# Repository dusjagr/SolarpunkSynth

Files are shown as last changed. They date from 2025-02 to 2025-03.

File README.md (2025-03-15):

# SolarpunkSynth 🌞🎹

A solar-powered synthesizer that creates experimental sounds, rhythmic patterns, and beats using minimal energy from the sun! This project embodies the spirit of solarpunk by combining sustainable energy with creative expression.

# Workshop Registration
https://sgmkcloud.ocloud.de/index.php/apps/forms/65qHgGpafZMqBaDL

## Description

The SolarpunkSynth is an ultra-low power consumption synthesizer that can be powered by:
- Silicon solar cells
- DIY DSSC (Dye-sensitized solar cells)
- Alternative power sources (mud batteries, potato power, coconut energy)
- Nearly depleted batteries (due to extremely low power requirements)

## Project Variants

This repository contains two versions of the SolarpunkSynth:

### 1. Original SolarpunkSynth
Located in [`/SolarPunkSynth`](./SolarPunkSynth)
- The original version of the solar-powered synthesizer
- Simple and elegant design
- Perfect for beginners and workshops
- Includes complete documentation and assembly instructions

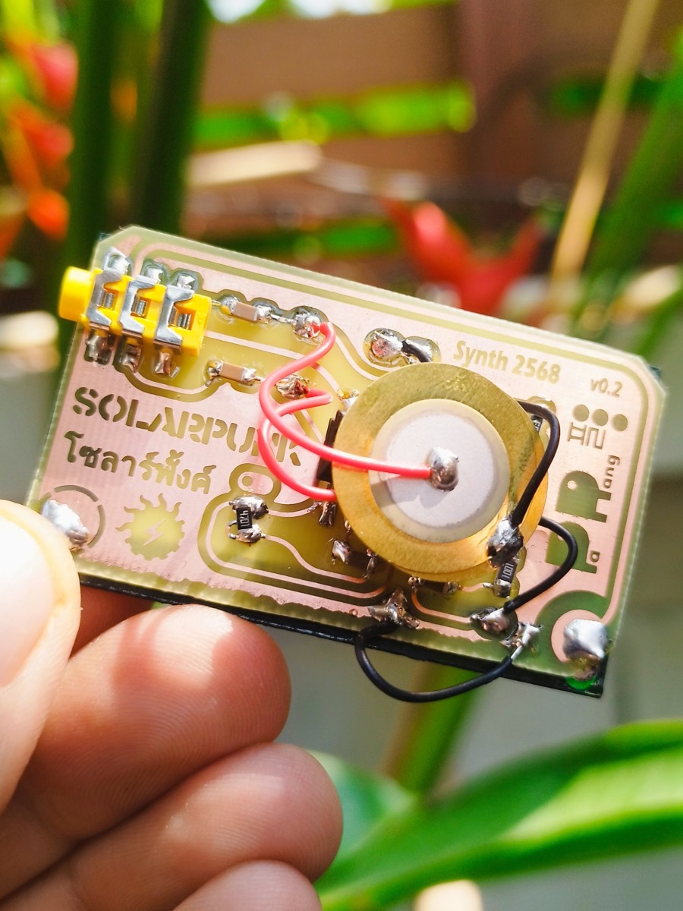
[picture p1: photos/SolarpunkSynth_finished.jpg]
Finished SolarpunkSynth


### 2. Digilog Edition
Located in [`/SolarSynth_digilog`](./SolarSynth_digilog)
- Enhanced version with digital-inspired aesthetics
- Developed for the Digilog exhibition in Taipei, Taiwan
- Features artistic PCB design with custom graphics
- Same core functionality with a unique visual style

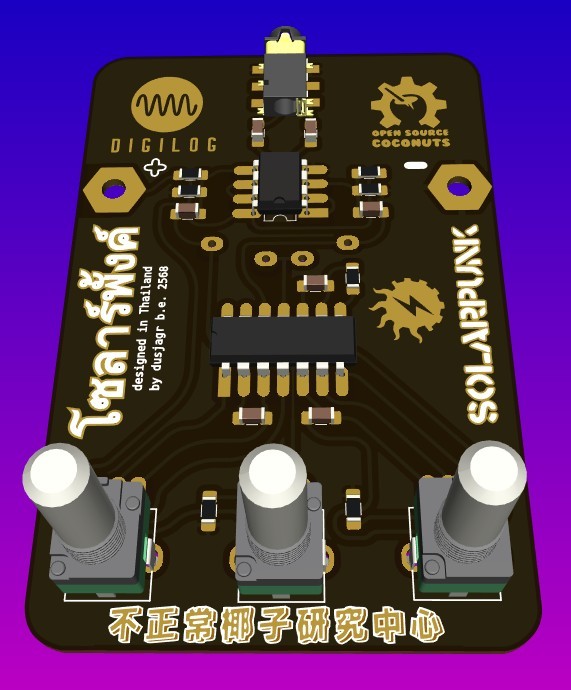
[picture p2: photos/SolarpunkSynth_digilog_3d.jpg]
SolarpunkSynth Digilog Edition


## Technical Details

The synthesizer is built around these key features:
- Based on hex-inverter chip (74HC14)
- Three interdependent oscillators coupled through piezo discs
- Ultra-low energy consumption (<0.5mA)
- Audio output via 3.5mm jack
- Organic, variable rhythms through unstable circuit states
- KiCad PCB design files included

### Technical Differences Between Variants

#### Original SolarpunkSynth
- Simple and robust circuit design
- Direct audio output from oscillator circuit
- Basic component selection for easy assembly
- Standard PCB layout optimized for functionality
- Ideal for workshops and educational purposes

#### Digilog Edition Enhancements
- Added MCP6002 dual op-amp for improved audio output buffering
- Enhanced signal conditioning with additional filtering capacitors
- Modified component values for better stability
- Custom footprint library optimized for artistic PCB layout
- Artistic PCB design with custom traces and visual elements
- ENIG finish recommended for superior aesthetic presentation
- Optional acrylic cover design for finished look and protection

### Schematic
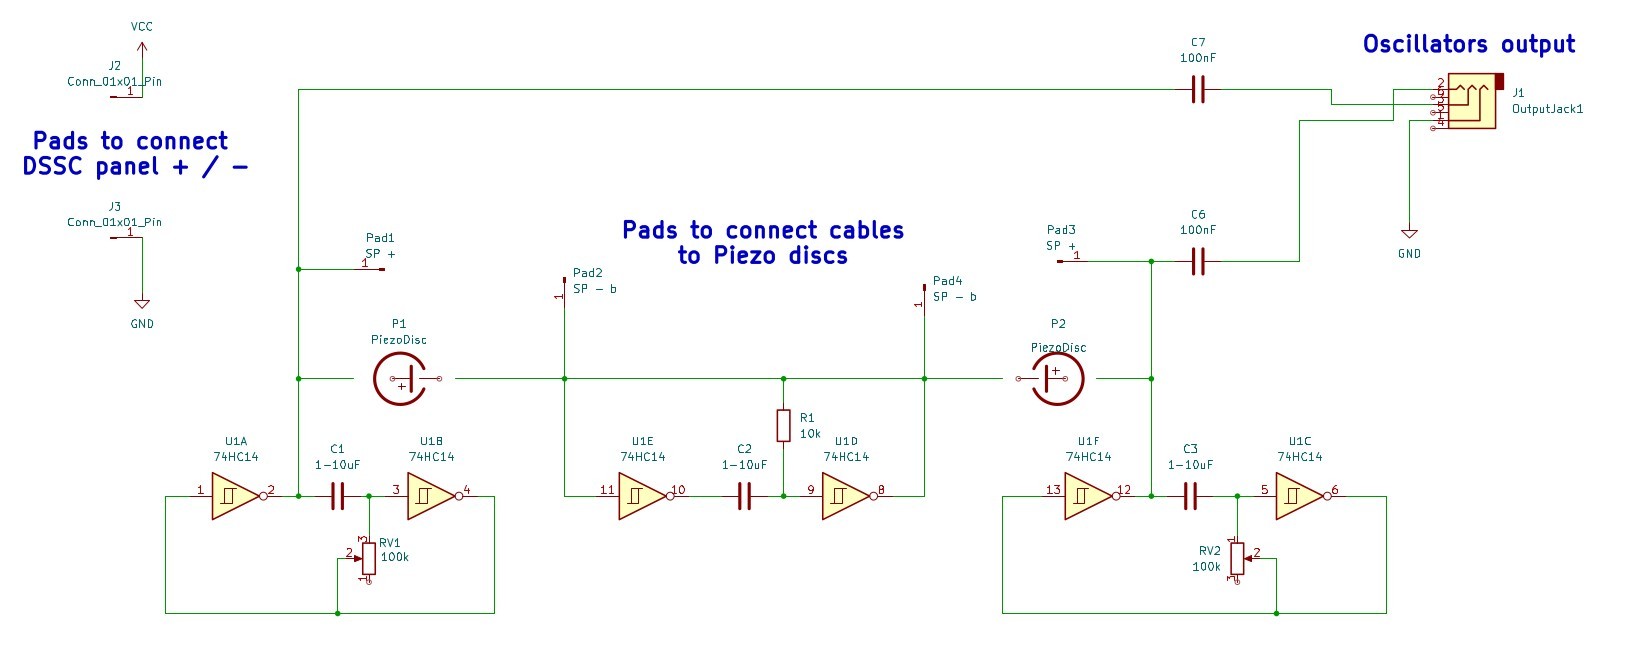
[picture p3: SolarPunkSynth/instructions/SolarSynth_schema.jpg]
SolarSynth Schema


You can also view the [minimal schematic as PDF](./SolarPunkSynth/instructions/DSSC_Synthminimal_schema.pdf).

## Assembly Instructions

### Original SolarpunkSynth

For the original SolarpunkSynth version:
- [Detailed Soldering Guide (PDF)](./SolarPunkSynth/instructions/SolderInstruction.pdf)
- [Soldering Guide (SVG)](./SolarPunkSynth/instructions/SolderInstruction.svg)
- **[Complete step-by-step assembly instructions](./SolarPunkSynth/README.md#detailed-step-by-step-assembly-instructions)** are included in the SolarPunkSynth README.md

### Digilog Edition

Instruction photos are available:

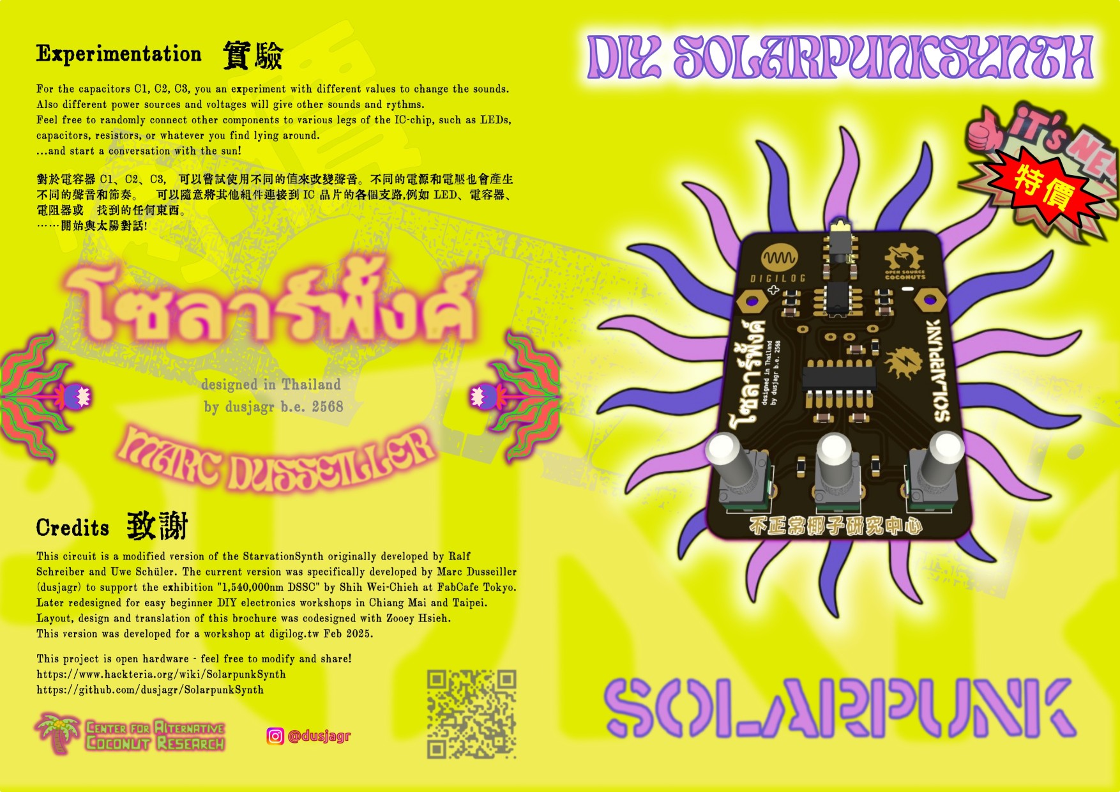
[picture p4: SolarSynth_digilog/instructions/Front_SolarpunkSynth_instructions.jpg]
Front Soldering Instructions

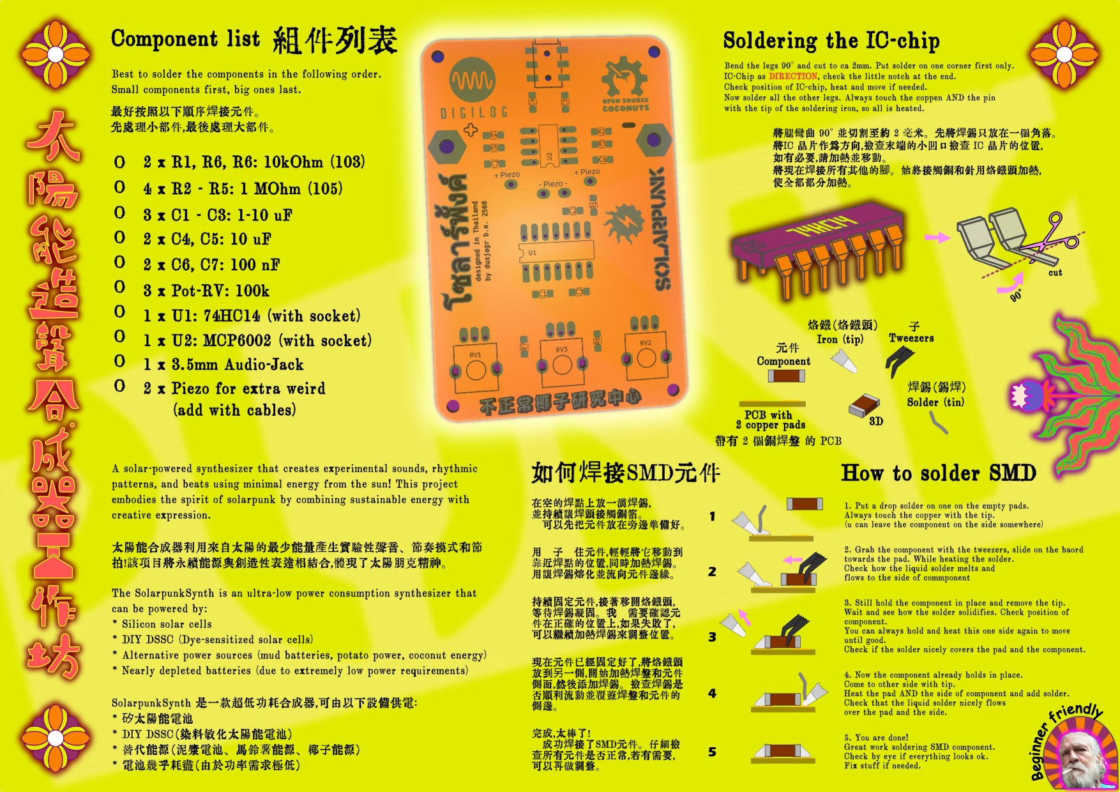
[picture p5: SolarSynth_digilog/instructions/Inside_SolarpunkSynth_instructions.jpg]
Inside Soldering Instructions


For the Digilog edition, additional documentation is available:
- [Leaflet Format Instructions (PDF)](./SolarSynth_digilog/instructions/SolarpunkSynth_SolderInstruction_leaflet.pdf)
- [Inside Pages (PDF)](./SolarSynth_digilog/instructions/SolarpunkSynth_SolderInstruction_leaflet_inside.pdf)
- [Outside Pages (PDF)](./SolarSynth_digilog/instructions/SolarpunkSynth_SolderInstruction_leaflet_outside.pdf)

## Repository Contents

- [`/SolarPunkSynth`](./SolarPunkSynth) - Original version KiCad files and documentation
  - [`/002_SolarPunkSynth_footprints.pretty`](./SolarPunkSynth/002_SolarPunkSynth_footprints.pretty) - Custom footprints for the PCB
  - [`/MASK`](./SolarPunkSynth/MASK) - PCB mask files and design assets
  - [`/instructions`](./SolarPunkSynth/instructions) - Assembly guides and schematics
  - [`/svg2shenzhen`](./SolarPunkSynth/svg2shenzhen) - SVG files for PCB artwork

- [`/SolarSynth_digilog`](./SolarSynth_digilog) - Digilog edition KiCad files
  - [`/3d_models`](./SolarSynth_digilog/3d_models) - 3D models of components
  - [`/DIY_pcb`](./SolarSynth_digilog/DIY_pcb) - DIY PCB patterns and masks for custom fabrication
  - [`/acrylicCover_digilog`](./SolarSynth_digilog/acrylicCover_digilog) - Design files for the optional acrylic protective cover
  - [`/gerber`](./SolarSynth_digilog/gerber) - Manufacturing files
  - [`/instructions`](./SolarSynth_digilog/instructions) - Enhanced assembly guides in multiple formats
  - [`/svg2shenzhen`](./SolarSynth_digilog/svg2shenzhen) - Custom PCB artwork files
  - [`BOM.ods`](./SolarSynth_digilog/BOM.ods) - Detailed bill of materials in OpenDocument Spreadsheet format

- [`/photos`](./photos) - Project photos and workshop documentation

## DIY PCB Fabrication

For those interested in creating their own PCBs at home or in makerspaces, the Digilog edition includes DIY PCB files:
- [`SolarSynth_MASK.png`](./SolarSynth_digilog/DIY_pcb/SolarSynth_MASK.png) - Printable mask pattern for toner transfer or photolithography
- [`SolarSynth_digilog_MASK.svg`](./SolarSynth_digilog/DIY_pcb/SolarSynth_digilog_MASK.svg) - Vector version of the mask for scaling and modifications

These files can be used with common DIY PCB fabrication methods like toner transfer, photolithography, or CNC milling.

## Acrylic Cover

The Digilog edition offers an optional aesthetic acrylic cover:
- [`acrylCover_digilog.dxf`](./SolarSynth_digilog/acrylicCover_digilog/acrylCover_digilog.dxf) - CAD file for laser cutting
- [`drawing.svg`](./SolarSynth_digilog/acrylicCover_digilog/drawing.svg) - Vector drawing for preview and modifications

The acrylic cover enhances the visual appeal while providing protection to the electronics.

## Workshop Information

A solar-powered synthesizer that creates experimental sounds, rhythmic patterns, and beats using minimal energy from the sun! This project embodies the spirit of solarpunk by combining sustainable energy with creative expression.

<figure>
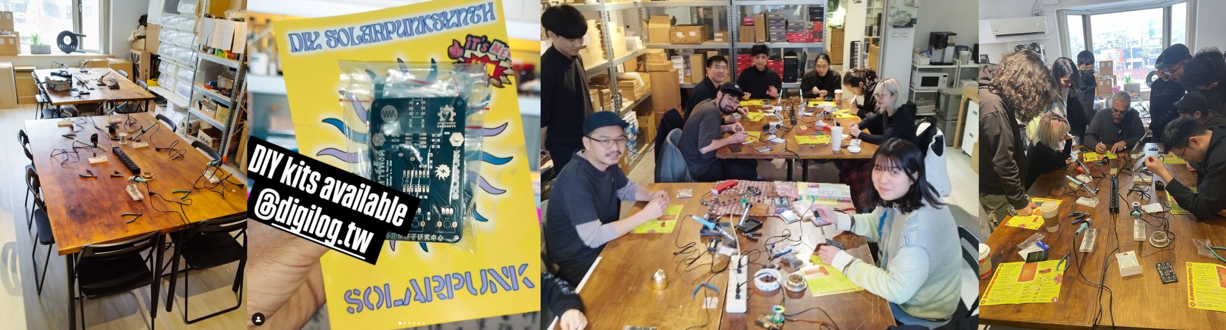
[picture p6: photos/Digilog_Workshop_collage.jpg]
Workshop Collage
  
  <figcaption><em>Impressions from the workshop at digilog, Taipei, February 2025</em></figcaption>
</figure>

This project is designed to be beginner-friendly and has been successfully taught in workshops across various locations including:
- Taipei, Taiwan (Digilog)
- Chiang Mai, Thailand
- Tokyo, Japan (FabCafe)

No prior electronics knowledge is required - just enthusiasm for experimental sounds and solar-powered creativity!

<figure>
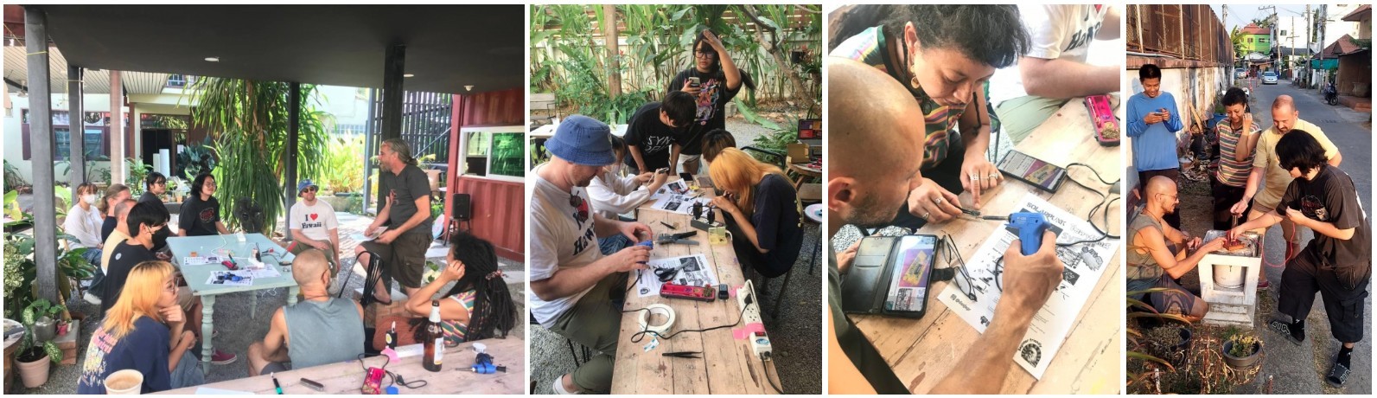
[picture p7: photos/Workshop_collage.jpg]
Workshop Collage
  
  <figcaption><em>Photos from the SolarpunkSynth Workshop at Parang Cafe & Art Stay, Chiang Mai, Thailand</em></figcaption>
</figure>

## Credits

This circuit is a modified version of the StarvationSynth originally developed by Ralf Schreiber and Uwe Schüler. The current version was specifically developed by Marc Dusseiller (dusjagr) to support the exhibition "1,540,000nm DSSC" by Shih Wei-Chieh at FabCafe Tokyo.

### Tools Used
- [svg2shenzhen](https://github.com/badgeek/svg2shenzhen) - An Inkscape extension that converts SVG drawings to KiCad PCB layouts, allowing for artistic and unrestricted PCB designs with support for any kind of shapes, drill pads, and edge cuts. Special thanks to Budi Prakosa ([@badgeek](https://github.com/badgeek)) for creating this amazing tool!
- KiCad - PCB design software

## Links

- [Project Wiki](https://www.hackteria.org/wiki/SolarpunkSynth)
- [Hackteria Network](http://hackteria.org/)
- [SGMK](https://mechatronicart.ch/)
- [Bitwäscherei Hackerspace](https://bitwaescherei.ch/)

## License

This project is open hardware - feel free to modify and share!

This project is licensed under the CERN Open Hardware License Version 2 - Permissive (CERN-OHL-P v2). This means you are free to:
- Study
- Modify
- Make
- Distribute

without any obligation to share your changes or modifications.

For more details, see the [LICENSE](./LICENSE) file.

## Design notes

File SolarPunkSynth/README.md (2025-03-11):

# Original SolarpunkSynth

This is the original version of the SolarpunkSynth - a solar-powered synthesizer designed for workshops and DIY enthusiasts.

Original SolarpunkSynth

## Features
- Simple and elegant PCB design
- Perfect for beginners and workshops
- Complete documentation and assembly instructions included
- Ultra-low power consumption (<0.5mA)
- Three interdependent oscillators

## Directory Contents
- `/002_SolarPunkSynth_footprints.pretty/` - Custom footprints for the PCB
- `/MASK/` - PCB mask files and design assets
- `/instructions/` - Detailed assembly guides and schematics
  - `SolderInstruction.pdf` - Step-by-step soldering guide
  - `SolderInstruction.svg` - Vector version of instructions
  - `SolarSynth_schema.jpg` - Circuit schematic
  - `DSSC_Synthminimal_schema.pdf` - Minimal schematic version
- `/svg2shenzhen/` - SVG files for PCB artwork

## Detailed Step-by-Step Assembly Instructions

Detailed soldering instructions are provided to help you build your own SolarpunkSynth:

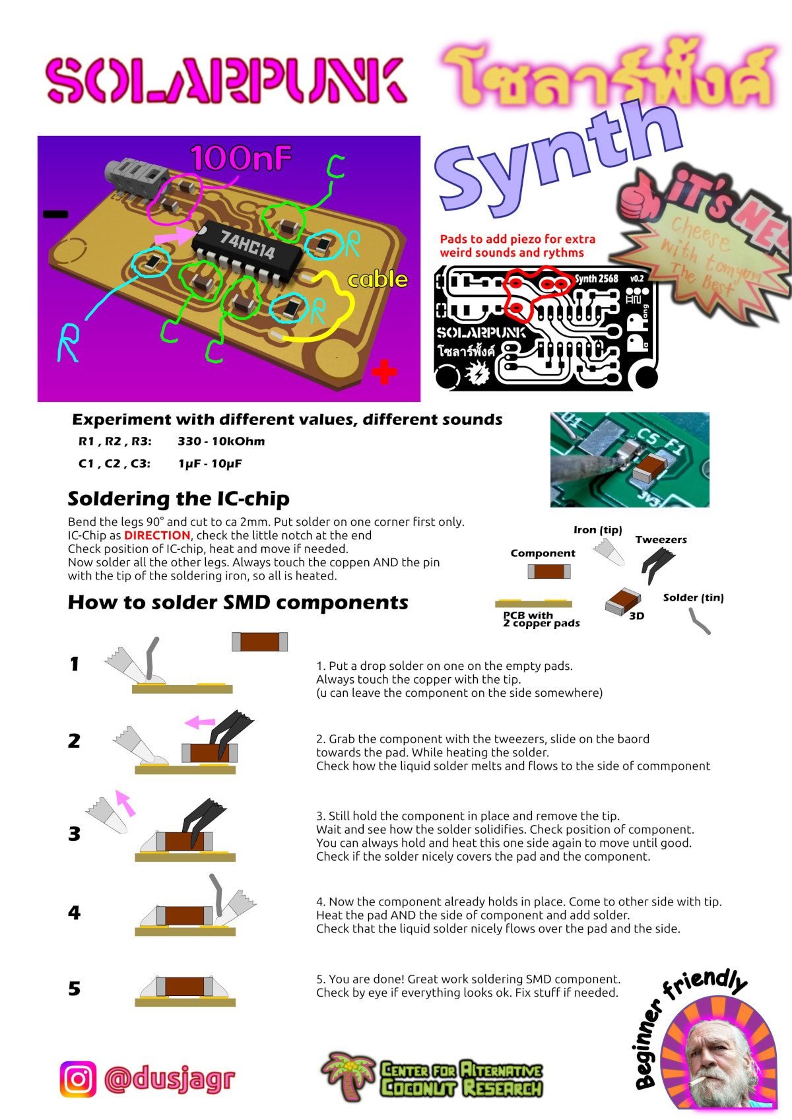
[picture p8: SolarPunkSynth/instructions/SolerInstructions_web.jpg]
Soldering Instructions


### Bill of Materials
- 1x PCB board
- 1x IC socket (14-pin DIP)
- 1x 74HC14 hex Schmitt trigger IC
- 3x Piezo discs
- 1x 3.5mm audio jack
- 1x 9V battery clip or solar cell connector
- Resistors:
  - 1x 1M ohm
  - 1x 470K ohm
  - 1x 330K ohm
  - 2x 100K ohm
  - 1x 10K ohm
- Capacitors:
  - 3x 0.1μF (ceramic)
  - 2x 10μF (electrolytic)

### Tools Required
- Soldering iron
- Solder (lead-free recommended)
- Wire cutters
- Tweezers (optional but helpful)
- Multimeter (for troubleshooting)

### Assembly Steps

#### 1. Prepare Your Workspace
- Find a well-ventilated area with good lighting
- Have all components sorted and ready
- Make sure your soldering iron is heated and ready

#### 2. Begin with Resistors
- Start by soldering the resistors first, as they are the lowest-profile components
- The resistors go in the positions marked on the PCB silkscreen
- Bend the resistor leads at 90° angles to match the hole spacing
- Insert them flush against the board
- Solder each connection and clip excess leads

#### 3. Add Capacitors
- Next, add the ceramic capacitors (0.1μF)
- For the electrolytic capacitors (10μF), make sure to observe the correct polarity - the negative side is marked with a stripe and should match the marking on the PCB

#### 4. Install the IC Socket
- Orient the socket so the notch matches the silkscreen
- Solder two opposite corner pins first to secure it in place
- Then solder the remaining pins

#### 5. Add the Audio Jack
- Insert the 3.5mm audio jack into its designated position
- Ensure it's sitting flat against the board
- Solder all pins securely

#### 6. Attach Piezo Discs
- Each piezo disc should be connected to its marked position
- The discs can be connected directly to the PCB or with short wires for flexibility
- For direct mounting, solder the piezo disc connections directly to the board
- For flexible mounting, solder short wires to the piezos and then to the board

#### 7. Connect Power
- Attach the battery clip or solar cell connector
- Make sure to observe correct polarity (red wire to + and black wire to -)

#### 8. Insert the IC
- Only after all other components are soldered, insert the 74HC14 IC into the socket
- Make sure the notch on the IC aligns with the notch on the socket
- Press firmly but gently to seat the IC properly

#### 9. Testing
- Connect a 9V battery or solar cell
- Plug headphones or an amplifier into the audio jack
- Tap or apply pressure to the piezo discs to create sound variations
- The circuit should immediately start generating sound

#### 10. Troubleshooting
If the circuit doesn't work:
- Check all solder joints for cold solder or bridges
- Verify the IC is correctly oriented and seated properly
- Confirm proper polarity of electrolytic capacitors and power connection
- Test voltage at various points with a multimeter
- Ensure the piezo discs are properly connected

### Playing Your SolarpunkSynth
- The synthesizer creates sounds through the interaction of three oscillators
- Each piezo disc influences one oscillator
- Try tapping, pressing, or even breathing on the piezo discs to change the sounds
- Experiment with different light intensities on the solar cell to alter sound characteristics
- Try connecting different audio outputs (headphones, amplifiers, speakers)

## Workshop Tips
- Recommended for groups of 5-15 participants
- Workshop duration: 2-3 hours
- No prior electronics experience required
- Tools needed: Soldering iron, solder, wire cutters

## Workshop Experience

SolarpunkSynth Workshop Experience

The SolarpunkSynth has been successfully used in numerous workshops, helping participants learn about electronics, solar power, and sound synthesis in an engaging hands-on environment.

## License
This project is licensed under the CERN Open Hardware License Version 2 - Permissive (CERN-OHL-P v2).

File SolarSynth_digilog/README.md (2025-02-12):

# SolarpunkSynth Digilog Edition

This is the Digilog edition of the SolarpunkSynth, specially developed for the Digilog exhibition in Taipei, Taiwan. This version features an artistic PCB design while maintaining the core functionality of the original SolarpunkSynth.

SolarpunkSynth Digilog Edition

## Features
- Enhanced PCB design with digital-inspired aesthetics
- Artistic circuit traces and visual elements
- Exhibition-ready presentation
- Improved audio output stage with op-amp buffer
- Ultra-low power consumption (<0.5mA)

## Technical Enhancements
- Added MCP6002 dual op-amp for better audio output buffering
- Enhanced signal conditioning with additional filtering
- Modified component values for improved stability
- Custom footprint library optimized for artistic PCB layout
- Polarized capacitors for better power filtering

## Directory Contents
- `/3d_models/` - 3D models of components for visualization
- `/gerber/` - Manufacturing files for PCB production
- `/svg2shenzhen/` - Custom PCB artwork files

## Exhibition History
- Digilog Exhibition, Taipei, Taiwan
- Part of the exploration of digital aesthetics in analog circuits
- Demonstrates the intersection of art and technology

## Technical Specifications
- Based on 74HC14 hex-inverter chip
- Three coupled oscillators using piezo discs
- MCP6002 dual op-amp for audio buffering
- Solar-powered operation
- 3.5mm audio output
- Artistic PCB design with custom traces

## PCB Design Process
The artistic PCB design was created using:
- [svg2shenzhen](https://github.com/badgeek/svg2shenzhen) - An Inkscape extension that transforms SVG artwork into KiCad PCB layouts, enabling complete creative freedom in PCB design with support for any shape and custom drill sizes
- Custom artwork designed specifically for the Digilog exhibition
- Careful consideration of both aesthetic and functional aspects

## Manufacturing Notes
- Gerber files are provided in the `/gerber/` directory
- PCB specifications:
  - 2-layer board
  - Custom silkscreen artwork
  - ENIG finish recommended for best aesthetic results

## Assembly
While the assembly process is similar to the original SolarpunkSynth, this version includes additional components:
1. MCP6002 dual op-amp in DFN-8 package
2. Additional filtering capacitors
3. Modified resistor values for the op-amp stage

Please refer to the schematic for detailed component values and connections.

## License
This project is licensed under the CERN Open Hardware License Version 2 - Permissive (CERN-OHL-P v2).

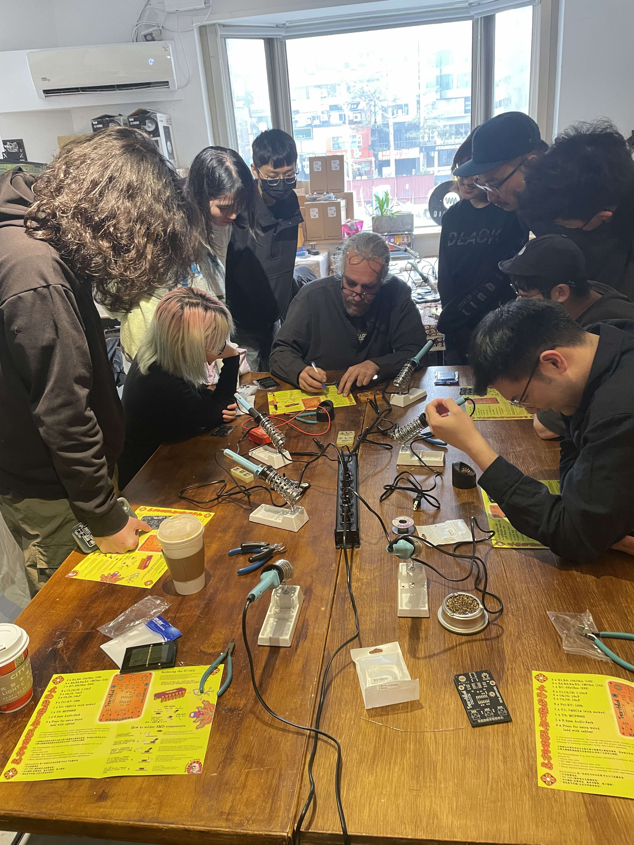
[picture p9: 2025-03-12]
photos/digilogWorkshop_02.jpg

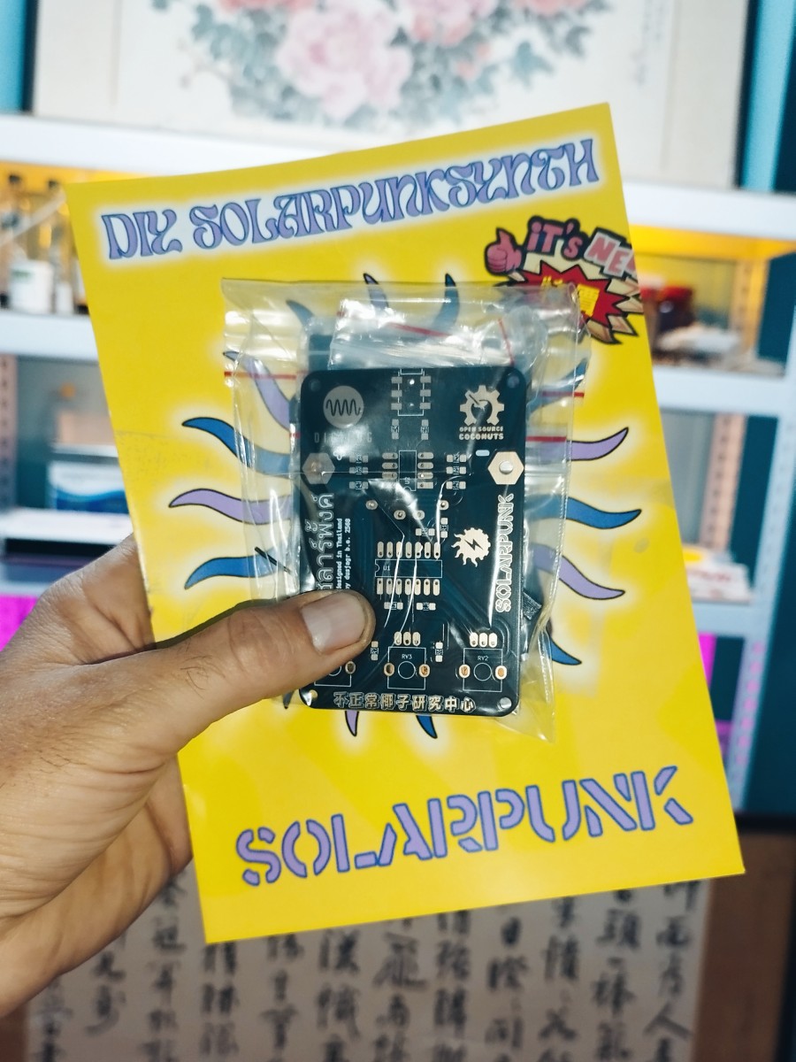
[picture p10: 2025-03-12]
photos/SolarpunkSynth_KIT.jpg

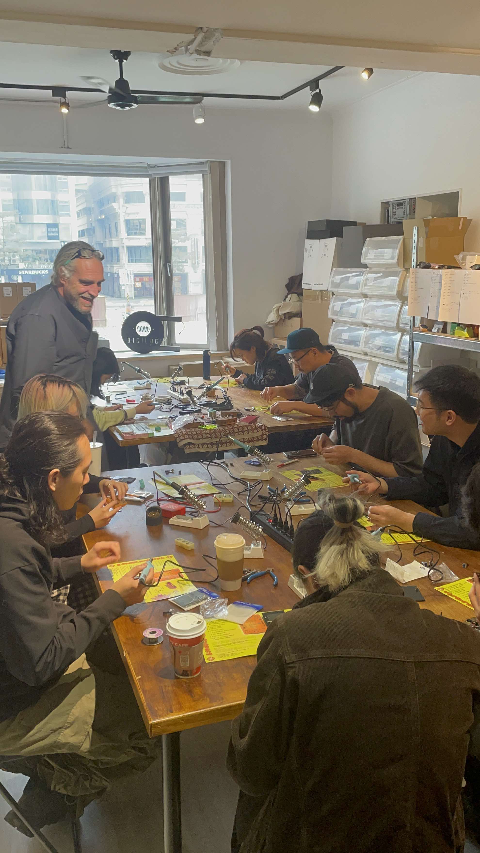
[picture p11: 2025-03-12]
photos/digilogWorkshop_01.jpg

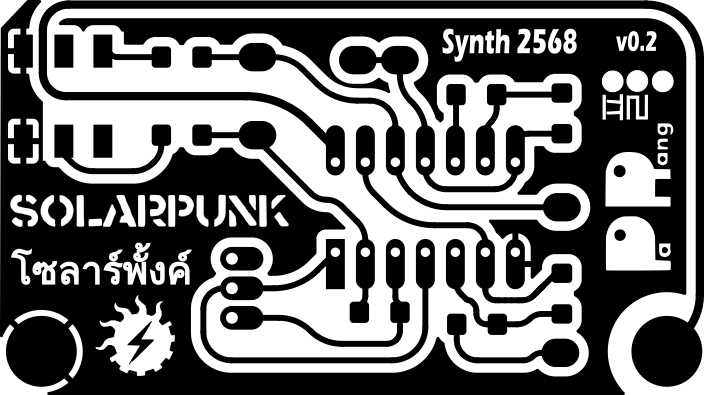
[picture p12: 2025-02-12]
SolarPunkSynth/MASK/SolarpunkSynth_parang.png

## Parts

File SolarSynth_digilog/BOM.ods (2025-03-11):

Id | Designator | Footprint | Quantity | Designation | Supplier and ref
10 | C3,C2,C1 | C_1210_noGND | 3 | 1-10uF
5 | C4,C5 | C_1210_noGND | 2 | C_Polarized
8 | C7,C6 | C_1210_noGND | 2 | 100nF
7 | edge1 | board_digilog | 1 | 5VBoard
11 | J1 | AUDIO-JACK-3.5mm_SMD_Hole | 1 | OutputJack1
2 | J3,J2 | SolarPad_VCC | 2 | Conn_01x01_Pin
12 | P1,P2 | Piezo_20mm | 2 | PiezoDisc
3 | Pad1,Pad3 | SolderPad_small | 2 | SP +
16 | Pad4,Pad2 | SolderPad_small | 2 | SP - b
6 | R1,R6 | R_1206_noGND | 2 | 10k
1 | R5,R4,R2,R3 | R_1206_noGND | 4 | 1M
14 | R7 | R_1206_noGND | 1 | 22k
4 | Ref** | graphix_digilog | 1 | Val**
17 | Ref** | back_graphix_digilog | 1 | Val**
13 | RV2,RV3,RV1 | RD901F-ALPHA-3D_longpads | 3 | 100k
15 | U1 | DIP-14_W7.62mm_LongerPads | 1 | 74HC14
9 | U2 | DIP-8_W7.62mm_LongerPads | 1 | MCP6002-xMC
 | R1,R6 |  | 2 | 10k
 | R5,R4,R2,R3 |  | 4 | 1M
 | R7 |  | 1 | 22k
 | C3,C2,C1 |  | 3 | 1-10uF
 | C4,C5 |  | 2 | C_Polarized
 | C7,C6 |  | 2 | 100nF
 | RV2,RV3,RV1 | RD901F-ALPHA-3D_longpads | 3 | 100k
 | U1 | DIP-14_W7.62mm_LongerPads | 1 | 74HC14
 | U2 | DIP-8_W7.62mm_LongerPads | 1 | MCP6002-xMC
 | J1 | AUDIO-JACK-3.5mm_SMD_Hole | 1 | OutputJack1

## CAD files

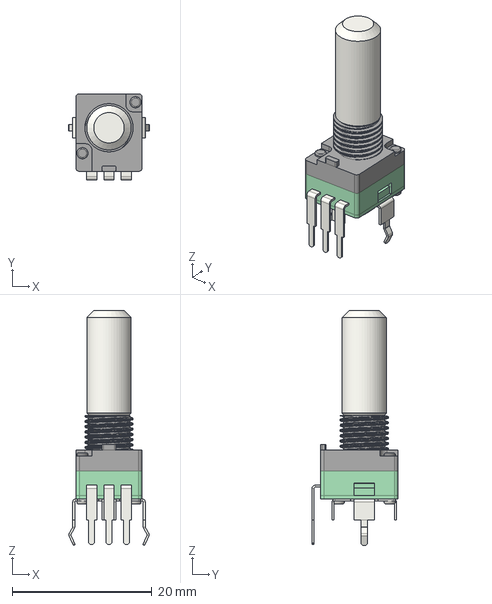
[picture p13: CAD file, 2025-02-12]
SolarSynth_digilog/3d_models/ALPHA-RD901F-40.step
11.5 x 12.4 x 33.6 mm

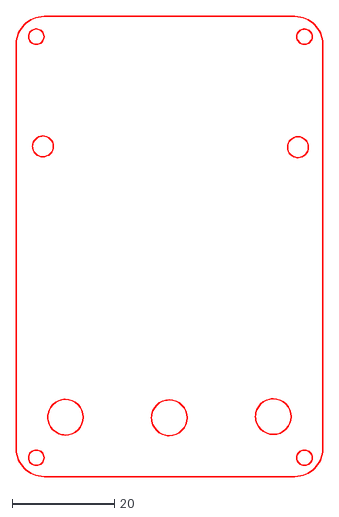
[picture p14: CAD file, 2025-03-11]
SolarSynth_digilog/acrylicCover_digilog/acrylCover_digilog.dxf
60.0 x 90.1

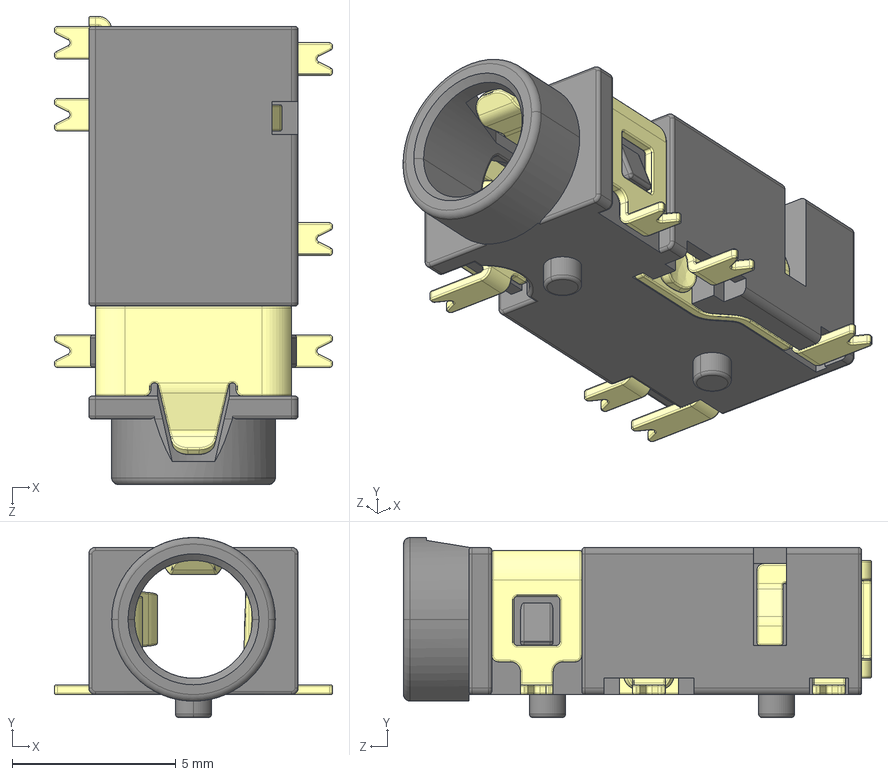
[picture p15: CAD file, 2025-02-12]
SolarSynth_digilog/3d_models/PJ311D_WPos.STEP
8.50 x 5.50 x 14.3 mm
001^PJ311D_WPos
002^PJ311D_WPos
003^PJ311D_WPos
004^PJ311D_WPos
005^PJ311D_WPos
006^PJ311D_WPos
007^PJ311D_WPos

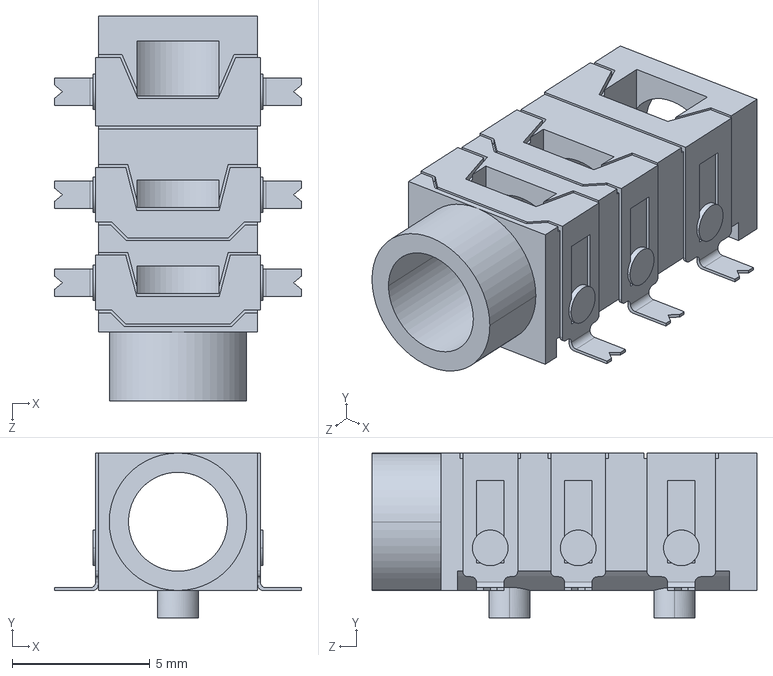
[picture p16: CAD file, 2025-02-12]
SolarSynth_digilog/3d_models/JackPJ313D.STEP
9.00 x 6.00 x 14.0 mm

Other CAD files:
SolarSynth_digilog/3d_models/JackPJ313D.SLDPRT

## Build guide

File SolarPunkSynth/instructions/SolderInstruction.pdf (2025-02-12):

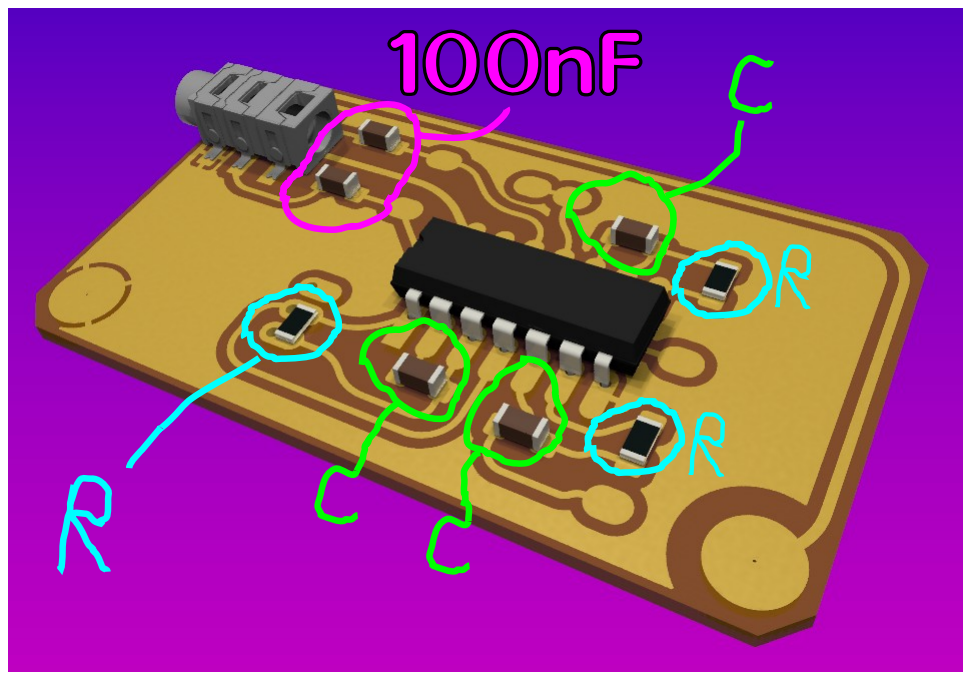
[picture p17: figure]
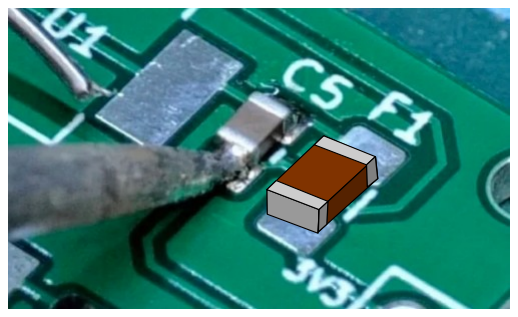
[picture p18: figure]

R1 , R2 , R3: | 330 - 10kOhm
C1 , C2 , C3: | 1µF - 10µF

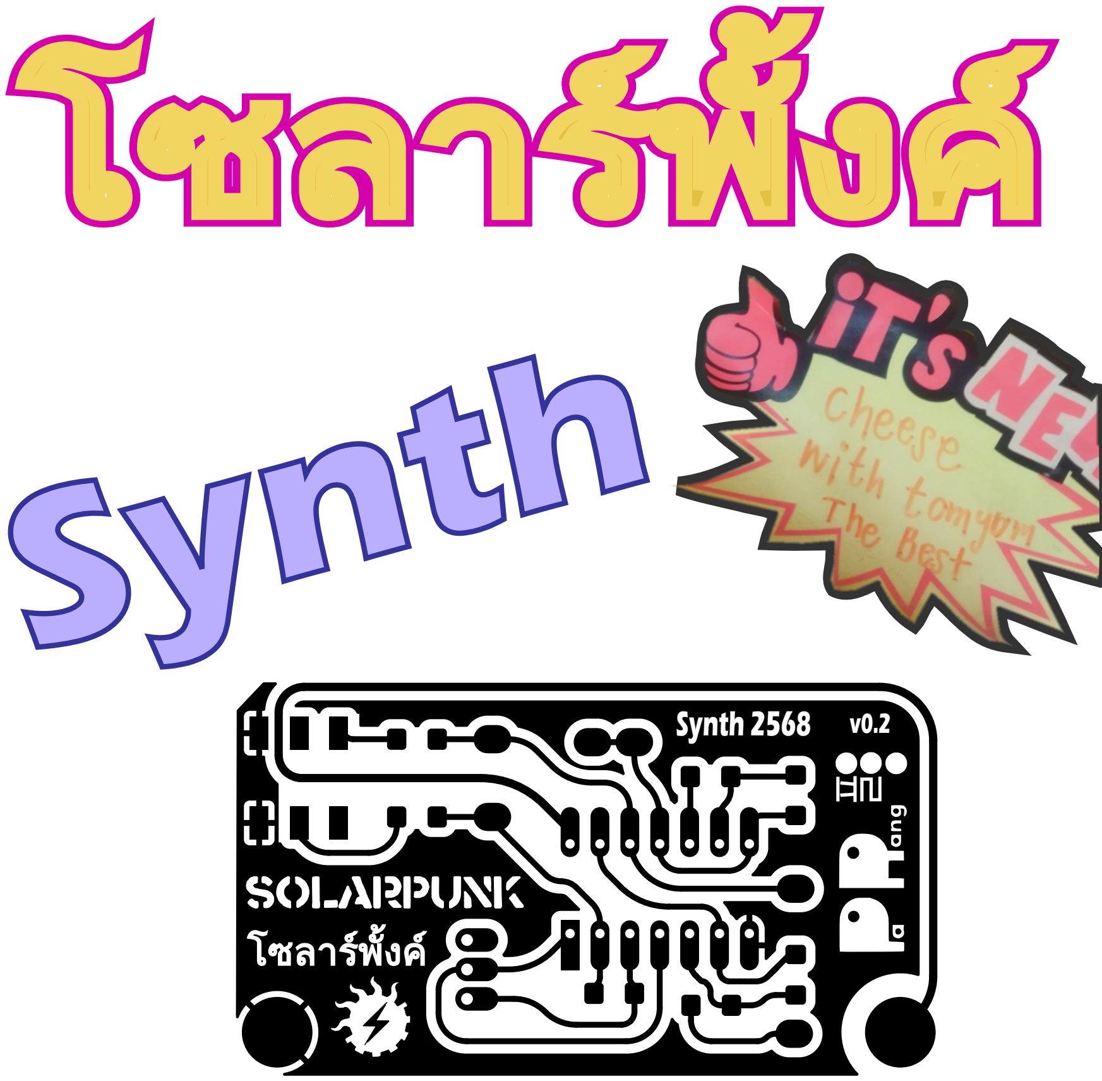
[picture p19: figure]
โซลารพัง้ค; Synth 2568 v0.2; โซลาร; Synth

## Experiment with different values, different sounds

# How to solder SMD components

1. Put a drop solder on one on the empty pads. Always touch the copper with the tip.
(u can leave the component on the side somewhere)

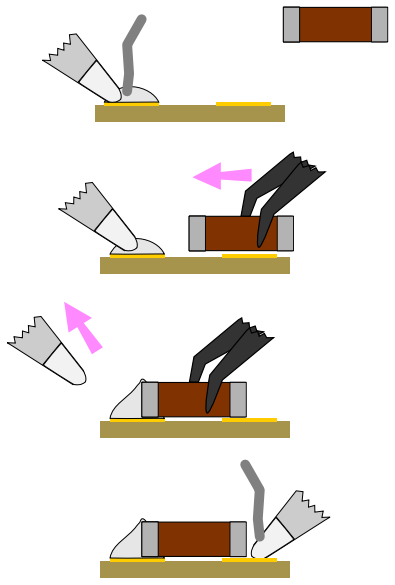
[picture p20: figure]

1

2

3

4

5

2. Grab the component with the tweezers, slide on the baord
towards the pad. While heating the solder.
Check how the liquid solder melts and flows to the side of commponent
3. Still hold the component in place and remove the tip.
Wait and see how the solder solidifies. Check position of component. You can always hold and heat this one side again to move until good. Check if the solder nicely covers the pad and the component.
4. Now the component already holds in place. Come to other side with tip. Heat the pad AND the side of component and add solder.
Check that the liquid solder nicely flows over the pad and the side.
5. You are done! Great work soldering SMD component.
Check by eye if everything looks ok. Fix stuff if needed.

Solder (tin)

Iron (tip)

Component

Tweezers

PCB with | 3D 2 copper pads

Bend the legs 90° and cut to ca 2mm. Put solder on one corner first only. Check position of IC-chip, heat and move if needed.
Now solder all the other legs. Always touch the coppen AND the pin with the tip of the soldering iron, so all is heated.

# Soldering the IC-chip

Be

gin

# ner friendly

Center for Alternative
Coconut Research

Center for Alternative
Coconut Research

# @dusjagr

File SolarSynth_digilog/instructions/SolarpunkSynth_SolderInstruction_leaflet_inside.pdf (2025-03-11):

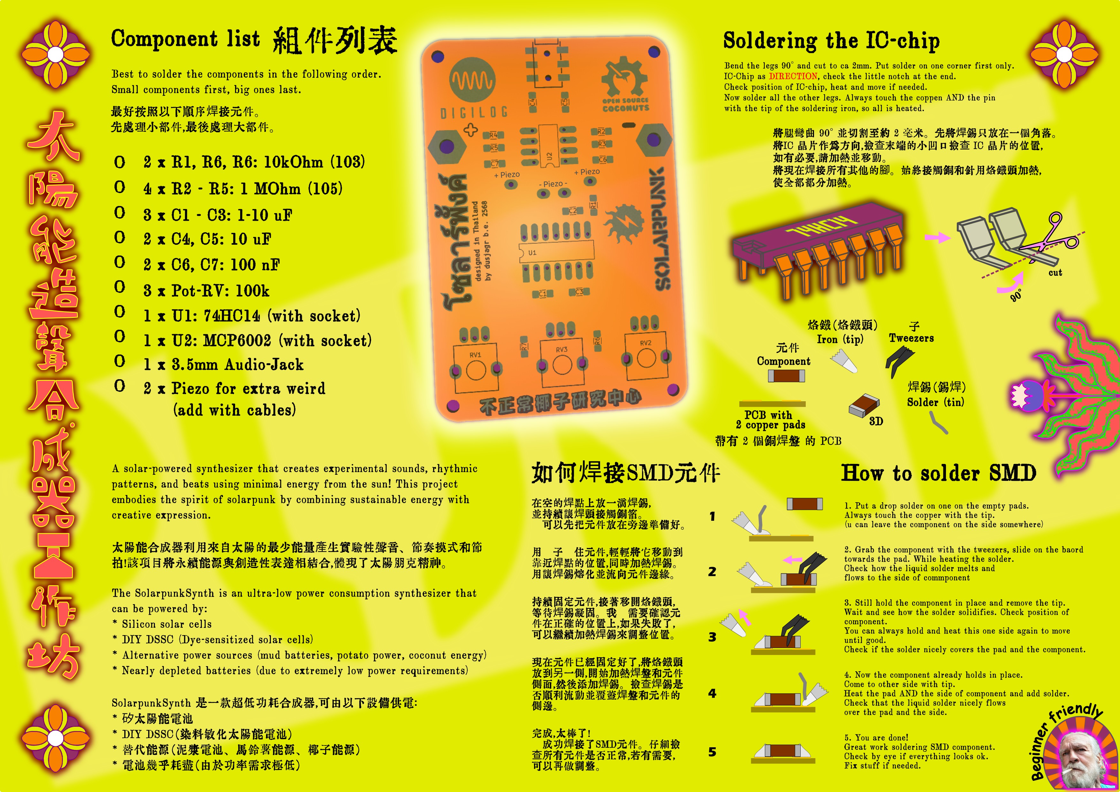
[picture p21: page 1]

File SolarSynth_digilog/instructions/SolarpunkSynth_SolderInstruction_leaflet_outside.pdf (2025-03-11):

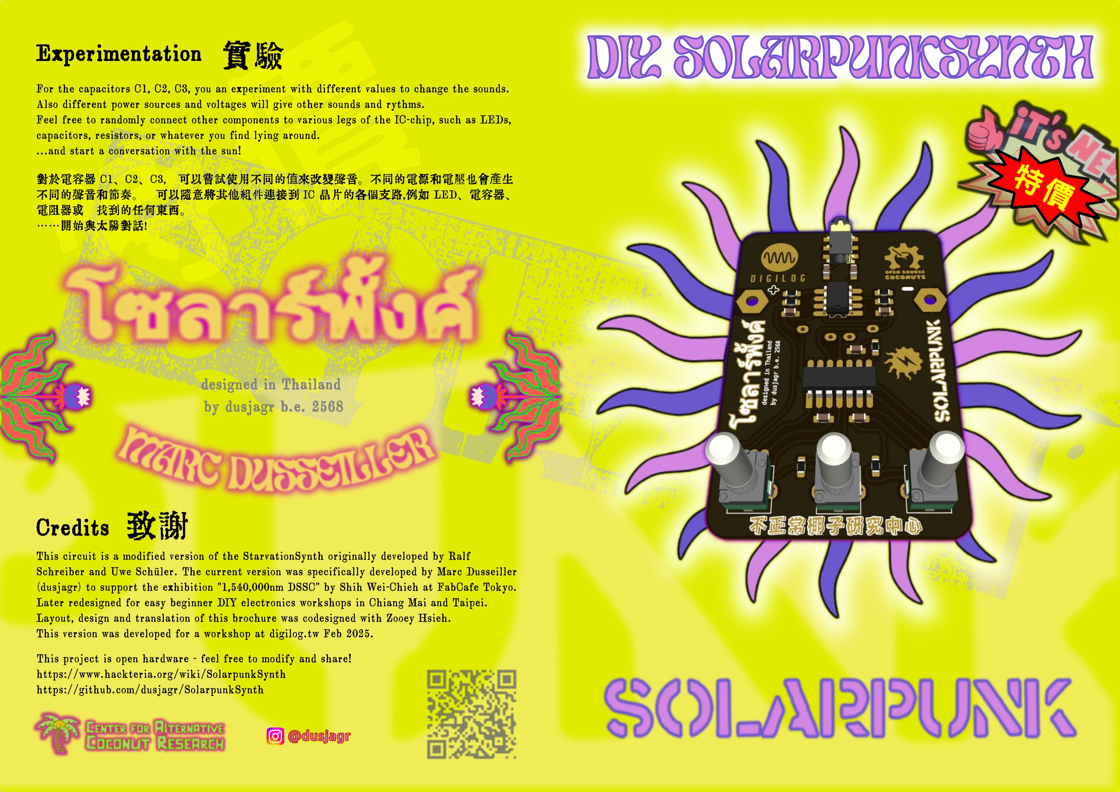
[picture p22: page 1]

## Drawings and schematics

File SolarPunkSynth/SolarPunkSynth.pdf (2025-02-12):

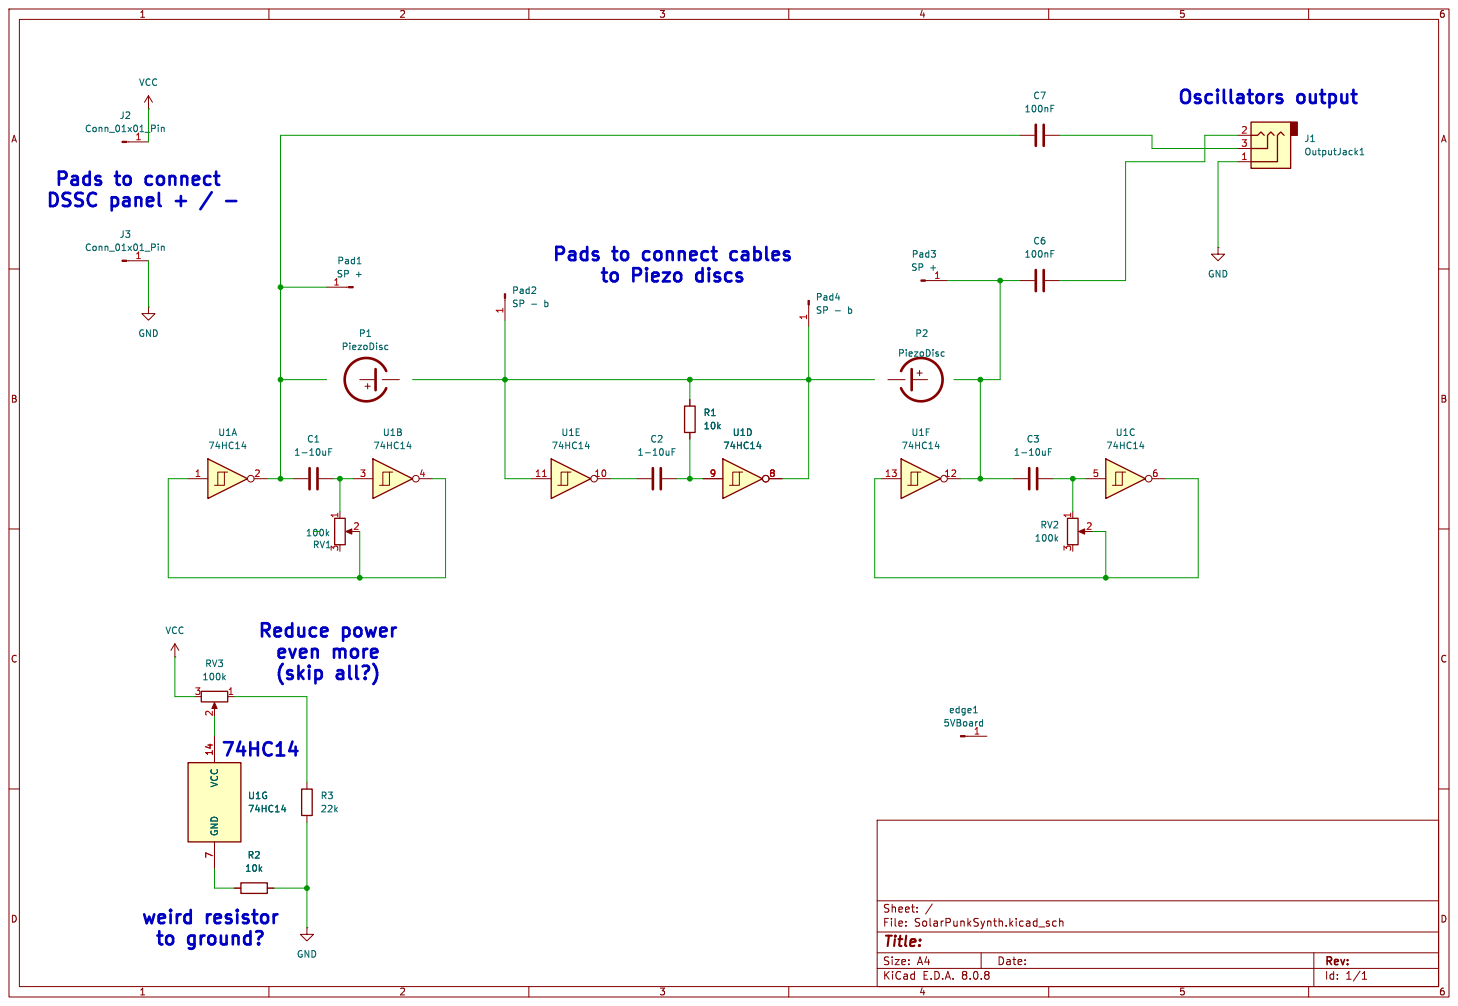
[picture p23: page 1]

Id: 1/1 Title: File: SolarPunkSynth.kicad_sch Sheet: /

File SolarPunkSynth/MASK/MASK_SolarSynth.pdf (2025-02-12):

# โซลาร

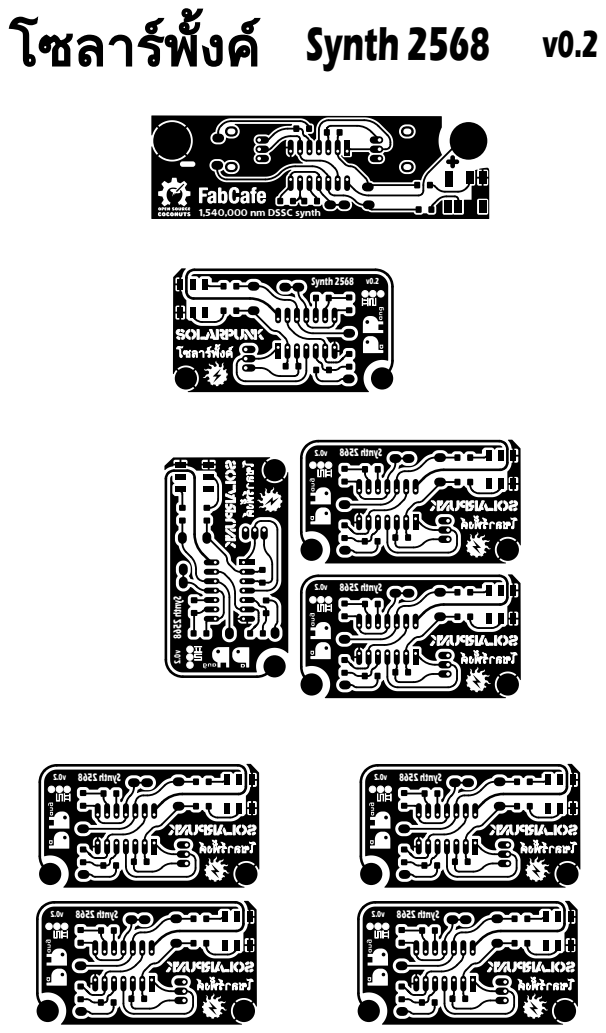
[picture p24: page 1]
โซลารพัง้ค; Synth 2568 v0.2; โ ซลารพั้งค

1,540,000 nm DSSC synth

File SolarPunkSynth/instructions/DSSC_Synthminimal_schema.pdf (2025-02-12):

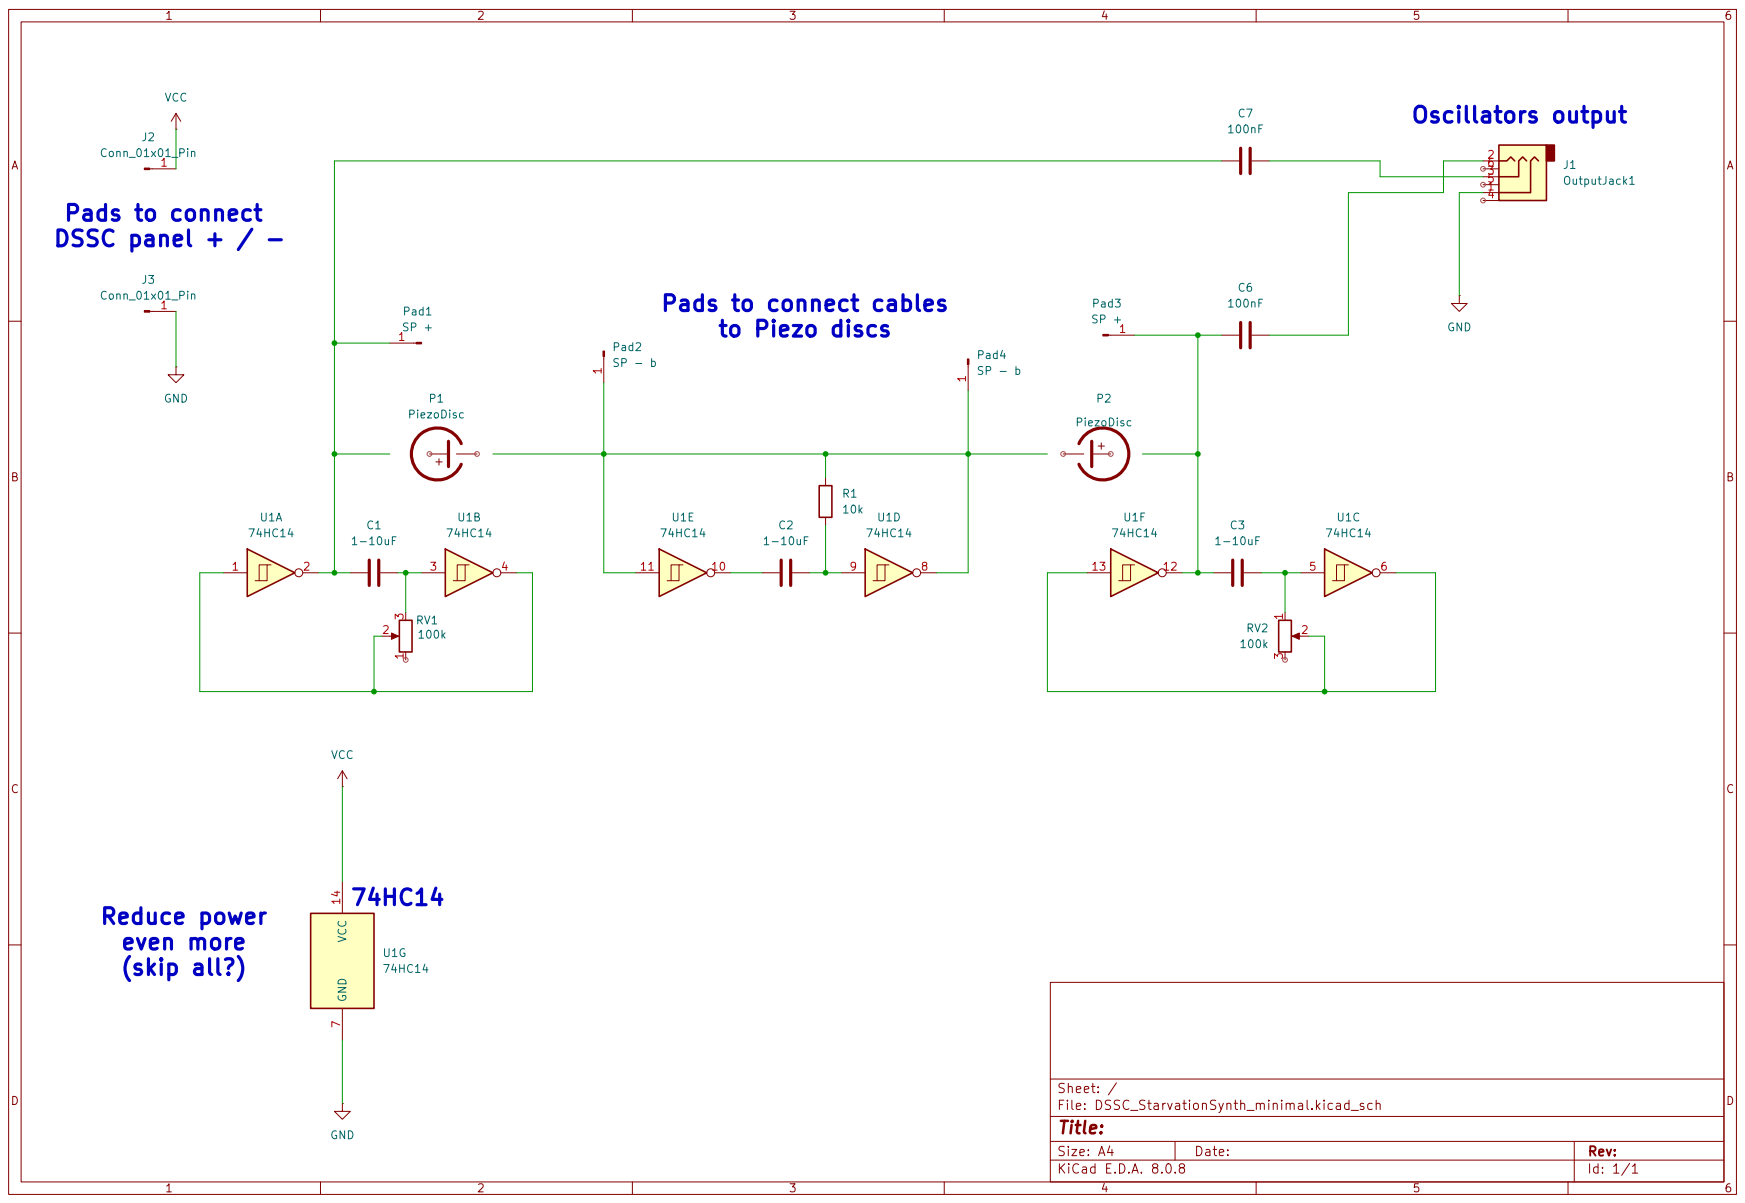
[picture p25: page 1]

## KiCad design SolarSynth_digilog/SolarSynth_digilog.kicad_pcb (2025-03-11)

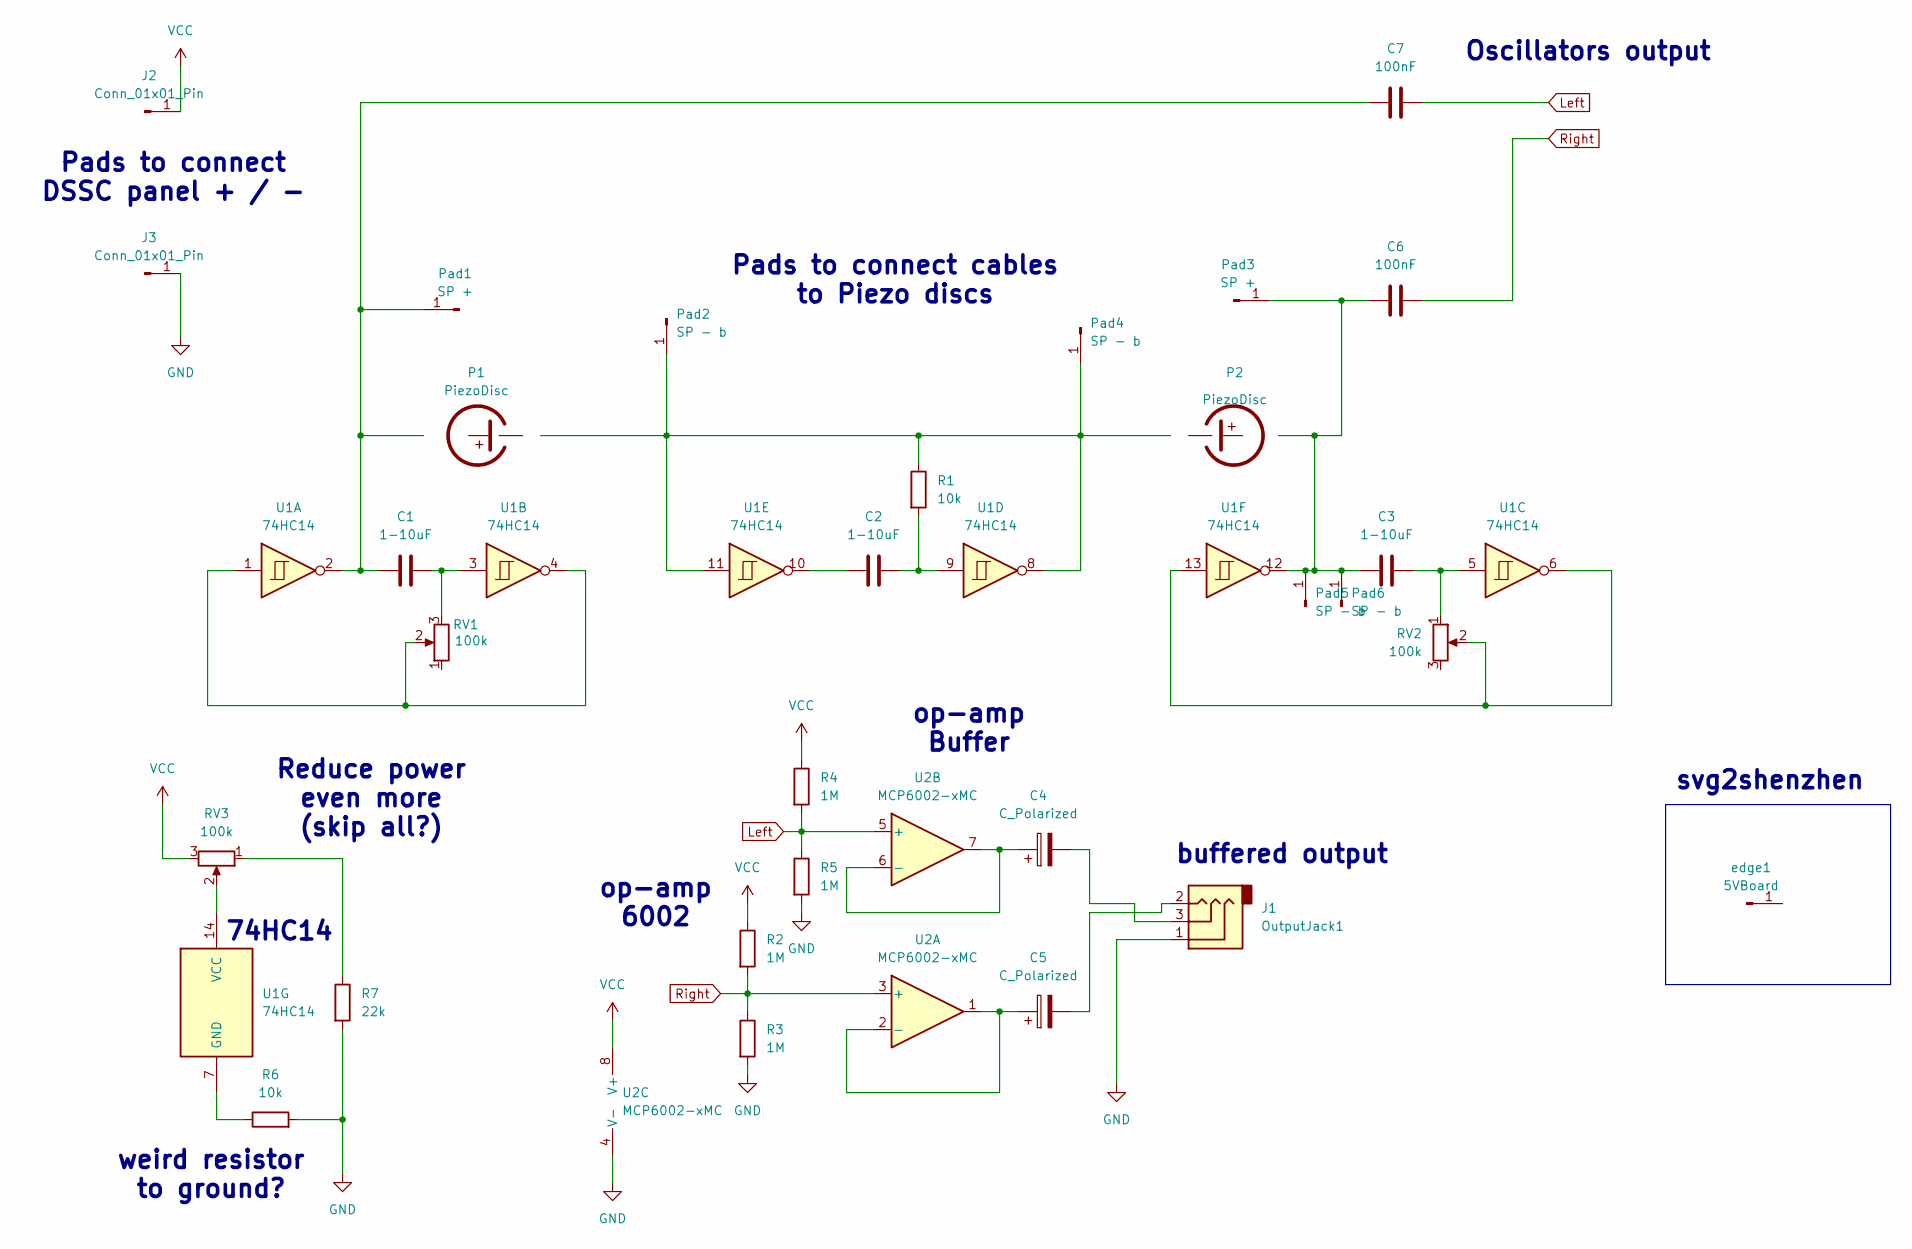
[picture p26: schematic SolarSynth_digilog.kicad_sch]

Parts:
C1, C2, C3: 1-10uF; C_1210_noGND
C4, C5: C_Polarized; C_1210_noGND
C6, C7: 100nF; C_1210_noGND
J1: OutputJack1; AUDIO-JACK-3.5mm_SMD_noHole
J2, J3: Conn_01x01_Pin; SolarPad_VCC
P1, P2: PiezoDisc; Piezo_20mm
Pad1, Pad3: SP +; SolderPad_small
Pad2, Pad4, Pad5, Pad6: SP - b; SolderPad_small
R1, R6: 10k; R_1206_noGND
R2, R3, R4, R5: 1M; R_1206_noGND
R7: 22k; R_1206_noGND
RV1, RV2: 100k; RD901F-ALPHA-3D_minis
RV3: 100k; RD901F-ALPHA-3D_longpads
U1: 74HC14; DIP-14_W7.62mm_LongerPads
U2: MCP6002-xMC; DIP-8_W7.62mm_LongerPads
edge1: 5VBoard; board_digilog

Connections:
GND: J1.1, J3.1, R3.2, R5.2, R6.2, R7.2, U2.4 (V-), U2.9 (V-)
Left: C7.2, R4.2, R5.1, U2.5 (+)
unnamed: C1.2, RV1.3, U1.3
unnamed: C2.1, U1.10
unnamed: C2.2, R1.2, U1.9
unnamed: C3.2, RV2.1, U1.5
unnamed: C4.2, J1.3
unnamed: C5.2, J1.2
unnamed: C1.1, C7.1, Pad1.1, U1.2
unnamed: Pad2.1, Pad4.1, R1.1, U1.8, U1.11
unnamed: C3.1, C6.1, Pad3.1, Pad5.1, Pad6.1, U1.12
unnamed: R7.1, RV3.1
unnamed: RV1.2, U1.1, U1.4
unnamed: RV2.2, U1.6, U1.13
unnamed: R6.1, U1.7 (GND)
unnamed: RV3.2, U1.14 (VCC)
unnamed: C5.1, U2.1, U2.2 (-)
unnamed: C4.1, U2.6 (-), U2.7
Right: C6.2, R2.2, R3.1, U2.3 (+)
VCC: J2.1, R2.1, R4.1, RV3.3, U2.8 (V+)

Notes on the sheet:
svg2shenzhen
Pads to connect cables to Piezo discs
Oscillators output
Reduce power even more (skip all?)
op-amp Buffer
op-amp 6002
weird resistor to ground?
74HC14
buffered output
Pads to connect DSSC panel + / -

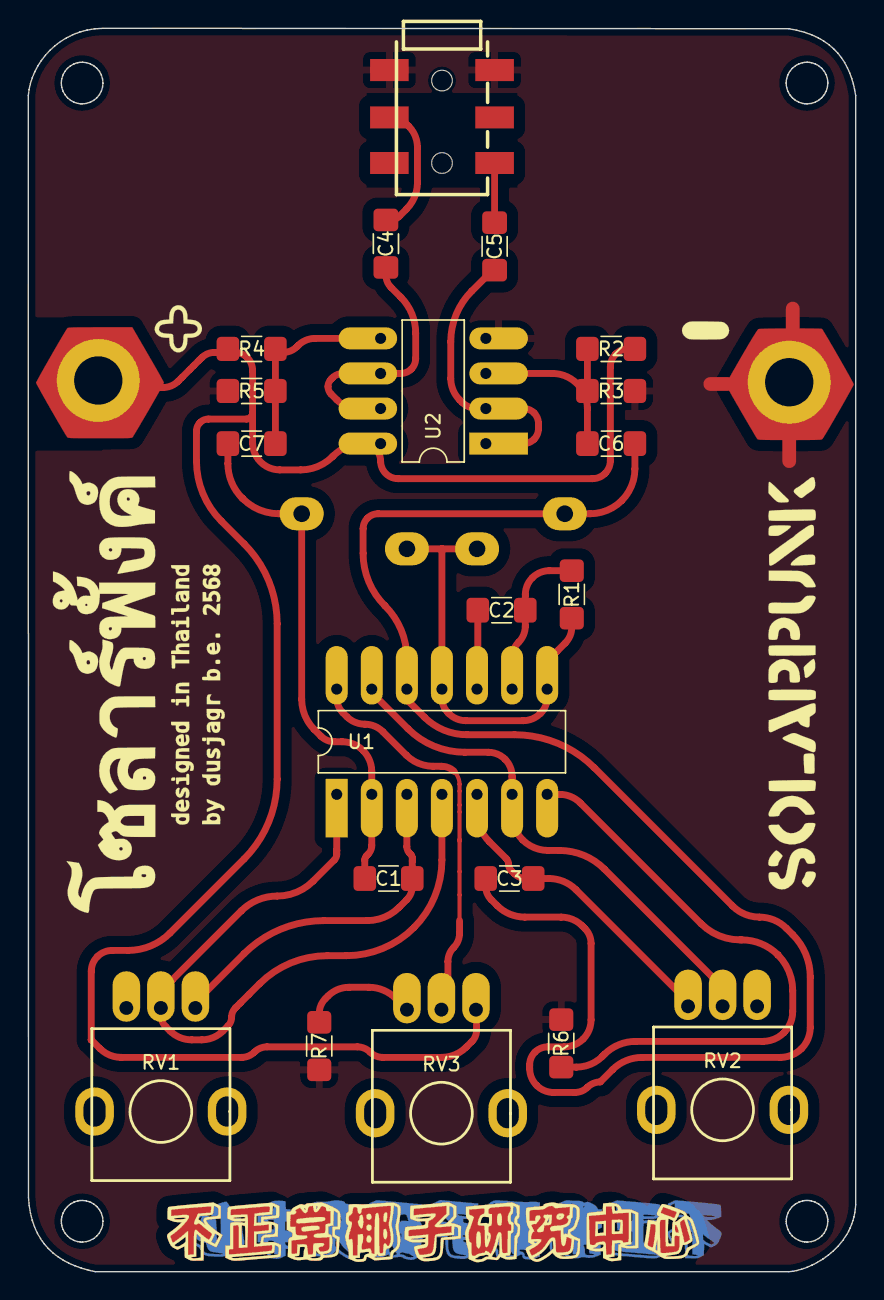
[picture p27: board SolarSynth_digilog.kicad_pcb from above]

Board: 2 copper layers, 59.9 x 90.0 mm, 31 parts (1 on the bottom side), 20 nets.

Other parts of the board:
Ref**: Val**; graphix_digilog
Ref**#2: Val**; back_graphix_digilog

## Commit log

2025-02-12 first commit both synth boards
    [SolarPunkSynth.kicad_pcb, SolarPunkSynth.kicad_sch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]
2025-02-12 Add .gitignore for KiCad project
2025-02-12 Add images and assembly instructions to README
2025-02-12 Update KiCad project files and add 3D models
    [ALPHA-RD901F-40.step, JackPJ313D.SLDPRT, JackPJ313D.STEP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]
2025-02-12 Update .gitignore with comprehensive KiCad ignore patterns and remove tracked cache files
2025-02-12 Remove KiCad backup directory from Git tracking
2025-03-11 Update documentation with detailed assembly instructions and add new resources for Digilog edition
    [BOM.ods, SolarSynth_digilog.kicad_pcb, acrylCover_digilog.dxf]
